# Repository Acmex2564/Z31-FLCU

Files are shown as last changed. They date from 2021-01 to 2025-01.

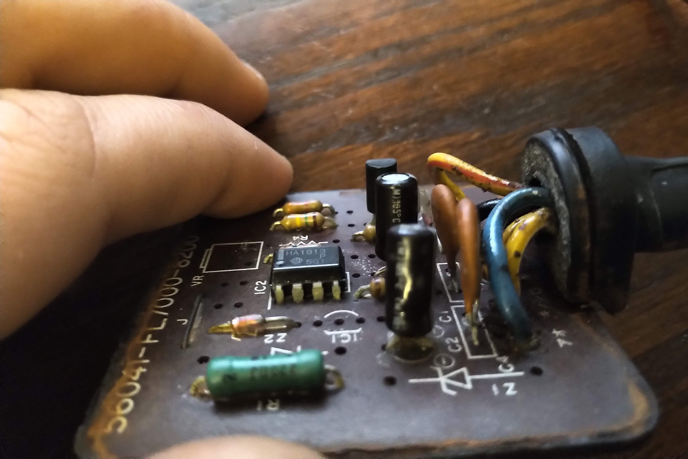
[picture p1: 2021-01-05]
ex_IMG_20210104_2121305.jpg

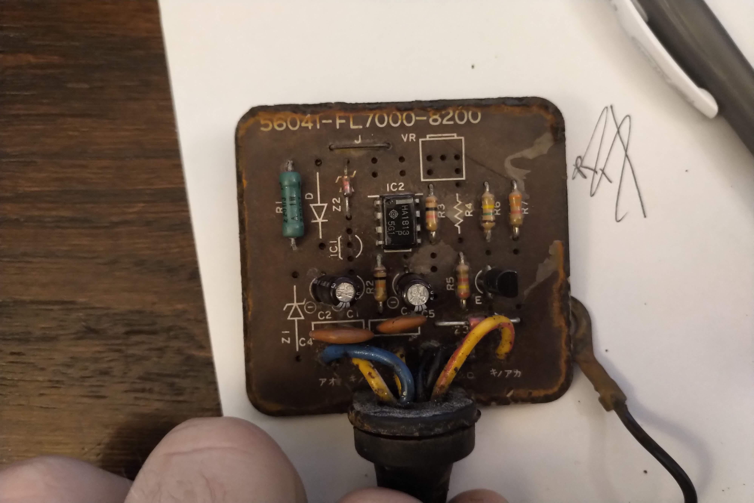
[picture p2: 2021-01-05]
ex_IMG_20200608_1817234.jpg

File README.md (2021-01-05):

# Z31-FLCU
Reverse Engineering of the 300zx (Z31) Analog -> Digital Fuel Tank Gauge Converter Unit

This is a small, silver box located under the hatch of very late Z31s, or cars that have had the original, linear-slide Tank Gauge Sending Unit (TGSU) replaced with the late swing-arm style. 

Analog and digital cars used TGSUs with different resistance curves, to suit the needs of the gauge cluster. The linear-slide parts often demonstrated poor accuracy and high wear-out rates, and the swing arm parts are a commonly sought upgrade. However, Nissan did not produce the same two variants of the later part. Instead, all were produced with the resistance curve for the analog cluster, and if you ordered the replacement part for a digital car you recieved the analog swing-arm, with a small converter box that adjusted the levels to suit the digital cluster.

Now, 30 years later, these simple, hastily-produced boxes are both rare and often affected by corrosion. Their environmental seals are poor, and cases are made of steel in a car with notoriously poor weatherproofing. Perfect for rusting away!

This repository contains my attempt at determing the schematic and method of operation for this tiny circuit. Perhaps one day it will also contain replacement PCB details. 

The key players on the board are:

Zener diode for IC voltage supply (YUP, they removed the actual VR IC to save costs!)
Current limiting resistor to save the Zener
Filter and reservoir caps for the power supply side
Hitachi HA1813P Analog Voltage Comparator
Hitachi D789 NPN transistor
Second Zener diode limiting the voltage from the cluster on the fuel-level sub-gauge sense circuit

In general terms, as far as I can make out this little box lowers the effective resistance for the fuel-level sub-gauge circuit based upon the input from the sending unit on the main gauge sender. I don't know much about digital electronics, and less about linear/analog ones, but it appears that the main level signal is left alone, and left more inaccurate, and the driver should rely on the digital "Fuel Volume remaining" readout on the dash.

Datasheets for the two Hitachi parts are located in the repository, because the datasheet for HA1813PS is difficult to find and I had already saved the other. 
Also found are images of the part in question, and it's wiring harness.

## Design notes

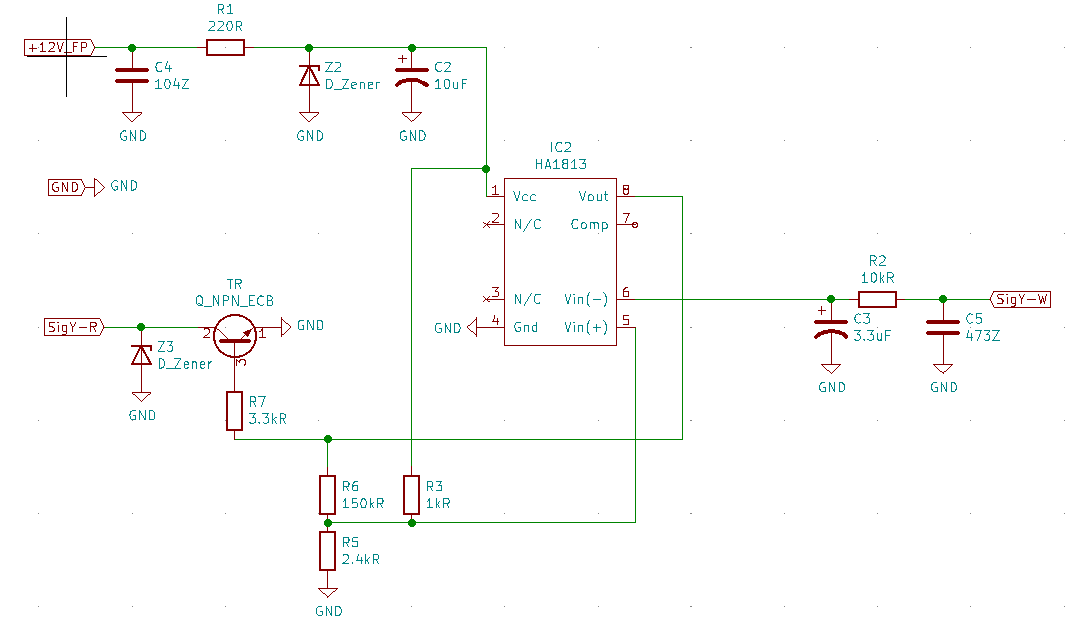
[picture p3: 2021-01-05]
Schematic.PNG

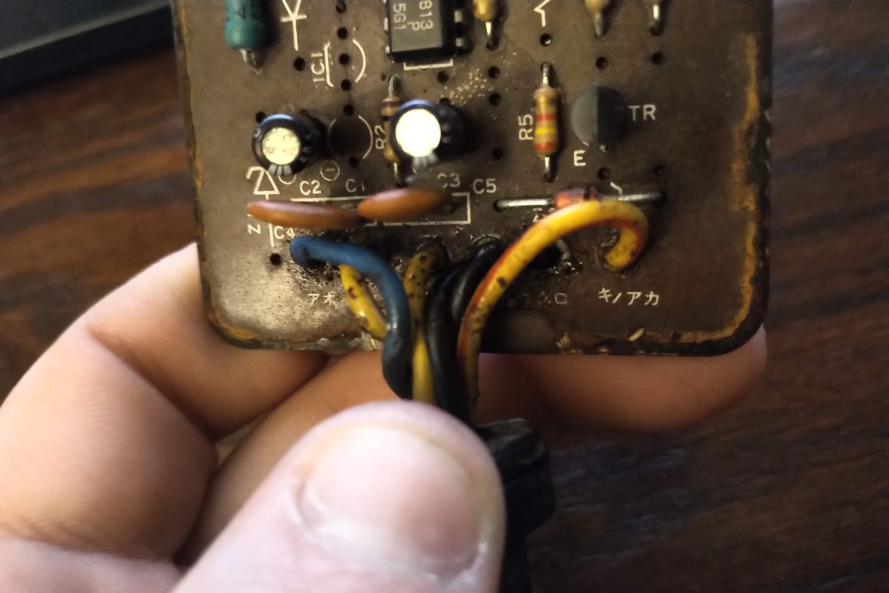
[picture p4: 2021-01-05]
ex_IMG_20210104_2121541.jpg

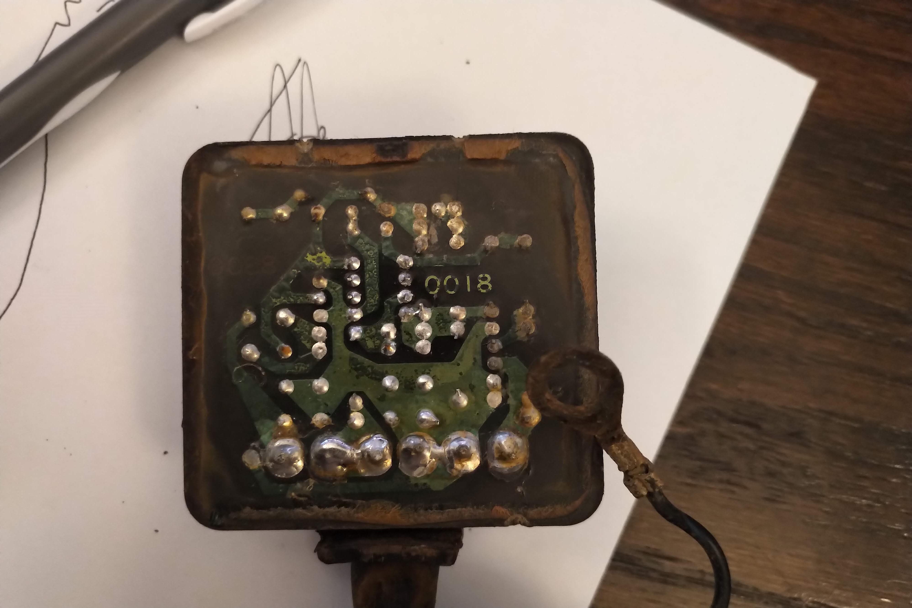
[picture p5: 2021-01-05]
ex_IMG_20200608_1817301.jpg

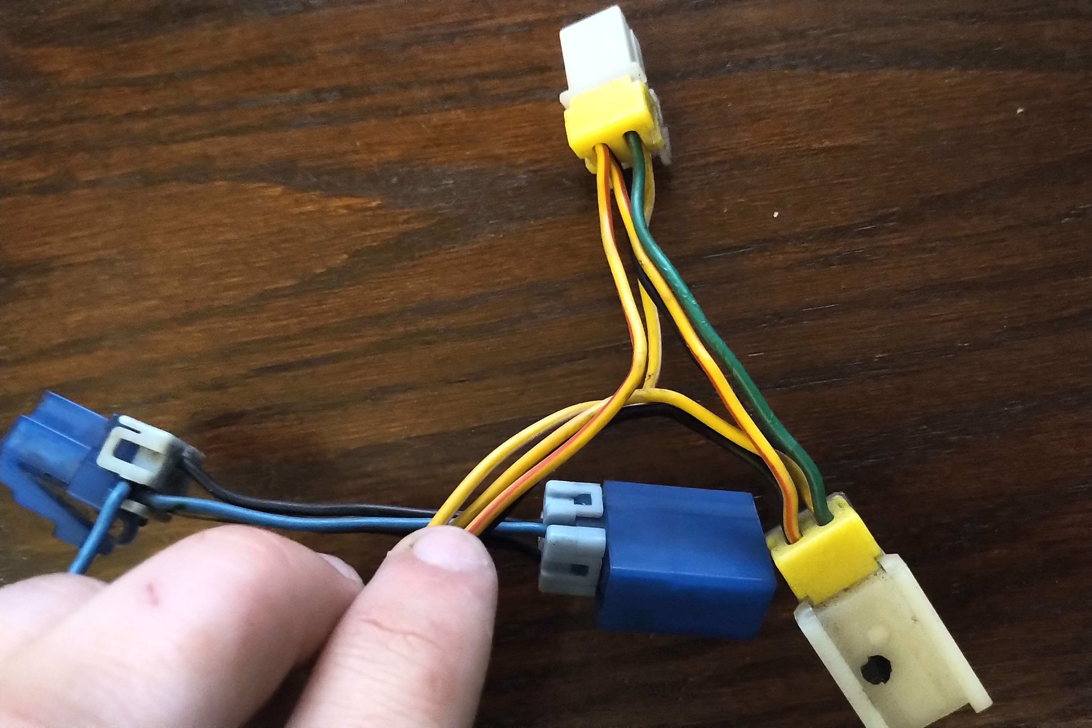
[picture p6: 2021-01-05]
ex_IMG_20210104_2122053.jpg

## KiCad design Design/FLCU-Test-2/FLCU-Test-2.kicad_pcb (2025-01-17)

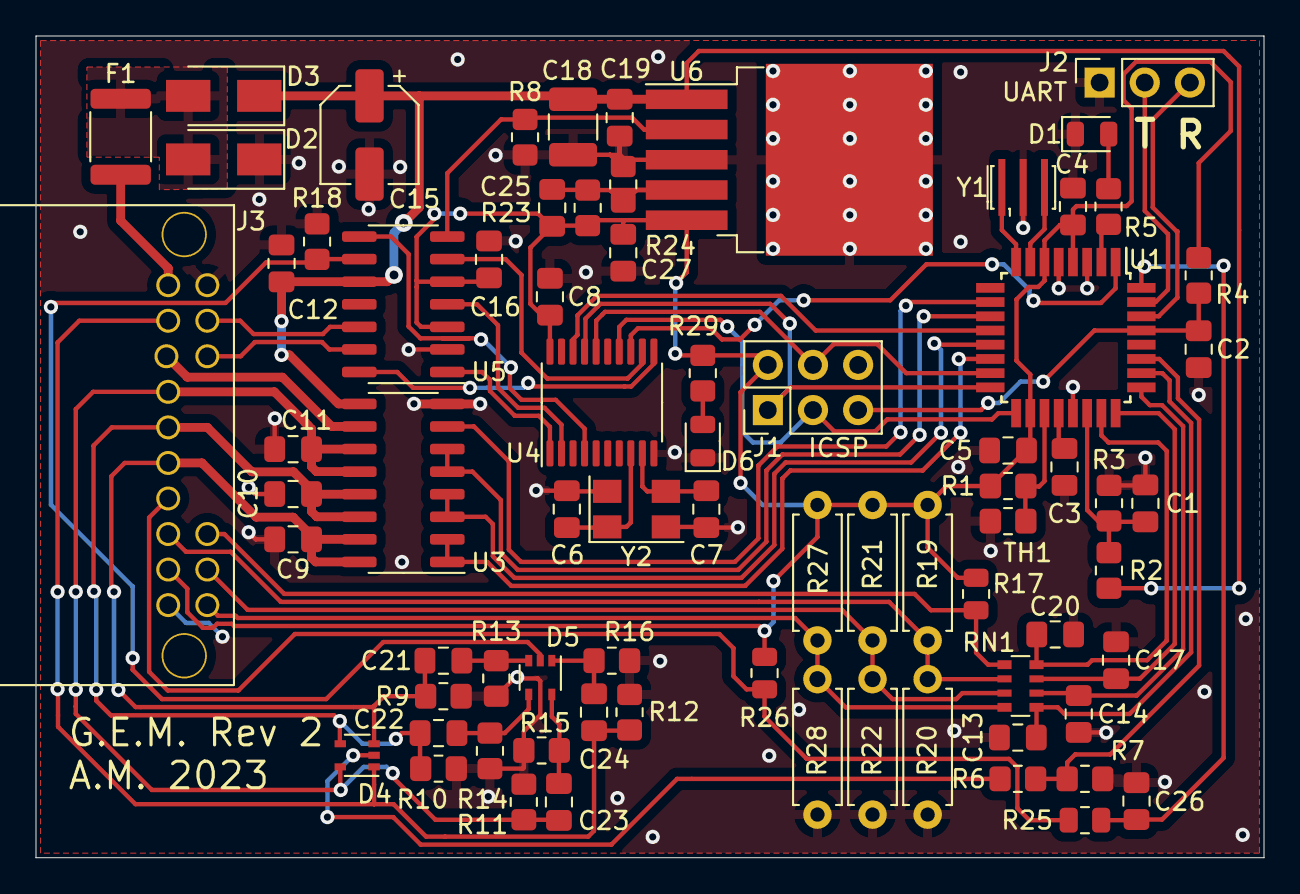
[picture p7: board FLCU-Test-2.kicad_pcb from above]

Board: 2 copper layers, 69.1 x 46.2 mm, 75 parts (0 on the bottom side), 58 nets.

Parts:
C1, C2, C3, C13, C14, C17, C19, C20, C26: 100nF; C_0805_2012Metric_Pad1.18x1.45mm_HandSolder
C4, C5: 1uF; C_0805_2012Metric_Pad1.18x1.45mm_HandSolder
C6, C7: 20pF; C_0805_2012Metric_Pad1.18x1.45mm_HandSolder
C8, C12, C16, C21, C22, C23, C24: 100n; C_0805_2012Metric_Pad1.18x1.45mm_HandSolder
C9, C10, C11, C27: 22uF; C_0805_2012Metric_Pad1.18x1.45mm_HandSolder
C15: 22uF; CP_Elec_5x5.7
C18: 1u; C_1210_3225Metric_Pad1.33x2.70mm_HandSolder
C25: N/A; C_0805_2012Metric_Pad1.18x1.45mm_HandSolder
D1, D6: LED; LED_0805_2012Metric
D2: SMAJ18CAQ-13-F; D_SMA
D3: D; D_SMA
D4, D5: MMBD4448HCQW; SOT-353_SC-70-5
F1: SMD1812P050TF/30; R_1812_4532Metric
J1: ICSP; PinHeader_2x03_P2.54mm_Vertical
J2: UART; PinSocket_1x03_P2.54mm_Vertical
J3: 0348260160
R1, R3: 47k; R_0805_2012Metric_Pad1.20x1.40mm_HandSolder
R2: 150k; R_0805_2012Metric_Pad1.20x1.40mm_HandSolder
R4, R6, R7, R8, R9, R10, R11, R12, R13, R14, R15, R16, R18: 10k; R_0805_2012Metric_Pad1.20x1.40mm_HandSolder
R5, R29: 1K; R_0805_2012Metric_Pad1.20x1.40mm_HandSolder
R17: R; R_0805_2012Metric
R19, R20, R21, R22, R27, R28: R; R_Axial_DIN0207_L6.3mm_D2.5mm_P7.62mm_Horizontal
R23, R24: N/A; R_0805_2012Metric_Pad1.20x1.40mm_HandSolder
R25: 47k; R_0805_2012Metric
R26: 10k; R_0805_2012Metric
RN1: 47K; R_Array_Convex_4x0603
TH1: 47k; R_0805_2012Metric_Pad1.20x1.40mm_HandSolder
U1: ATmega328-AU; TQFP-32_7x7mm_P0.8mm
U3: ULN2003ADR; SOIC-16_3.9x9.9mm_P1.27mm
U4: MCP2515-xST; TSSOP-20_4.4x6.5mm_P0.65mm
U5: TJR1443; SO-14_3.9x8.65mm_P1.27mm
U6: NCV4276B; TO-263-5_TabPin3
Y1: 16MHz; Resonator_SMD_Murata_CSTxExxV-3Pin_3.0x1.1mm_HandSoldering
Y2: 8MHz; Crystal_SMD_5032-4Pin_5.0x3.2mm

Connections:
+5V: C4.2, C5.1, C8.2, C16.2, C25.1, C27.1, J1.2, J3.15, R1.1, R4.1, R17.1, R19.1, R21.1, R23.1, R26.1, R27.1, R29.1, U1.4 (VCC), U1.6 (VCC), U1.18 (AVCC), U4.20 (VDD), U5.3 (Vcc), U5.5 (Vio), U6.5 (OUT)
+12V: C12.2, C15.1, C18.1, C19.1, D3.1 (K), R2.1, U3.9 (COM), U5.10 (Vbat), U6.1 (IN)
+12V_BATTERY: F1.2, J3.7
+12V_IGN: C24.1, D4.1 (A), J3.8, R12.1
/A1_In: J3.6, R27.2, R28.1, RN1.4 (R4.1)
/A2_In: J3.5, R21.2, R22.1, RN1.3 (R3.1)
/A3_In: J3.14, R19.2, R20.1, RN1.2 (R2.1)
/A4_In: J3.4, R17.2, RN1.1 (R1.1)
/CAN_EN: U4.12 (~RX0BF), U5.6 (EN)
/CAN_ERR: U4.4 (~TX0RTS), U5.8 (~ERR)
/CAN_RX: U4.2 (RXCAN), U5.4 (RXCAN)
/CAN_STB: U4.11 (~RX1BF), U5.14 (~STB_N)
/CAN_TX: U4.1 (TXCAN), U5.1 (TXCAN)
/D1_INT_In: J3.13, R25.2, R26.2
/D4: U1.10 (PD6), U3.7 (I7)
/Extra-Out: J3.9, U3.10 (O7)
/Low-Level-Warning-Out: C11.1, C23.1, D4.5 (A), J3.10, R11.1, U3.11 (O6), U3.12 (O5)
/Main-Level-Out: C10.1, C22.1, D4.4 (A), J3.11, R10.1, U3.13 (O4), U3.14 (O3)
/Module-Temperature: R1.2, TH1.1, U1.19 (ADC6)
/Module_Voltage: C1.2, R2.2, R3.1, U1.22 (ADC7)
/POSTFUSE: D2.2 (A2), D3.2 (A), F1.1
/PWM1: U1.13 (PB1), U3.3 (I3), U3.4 (I4)
/PWM2: U1.11 (PD7), U3.5 (I5), U3.6 (I6)
/PWM3: U1.14 (PB2), U3.1 (I1), U3.2 (I2)
/Spare-Analog: C20.2, RN1.8 (R1.2), U1.23 (PC0)
/Sub-Level-Out: C9.1, C21.1, D4.3 (A), J3.12, R9.1, U3.15 (O2), U3.16 (O1)
/VREG_INH: R8.1, U5.7 (INH), U6.2 (~INH)
/Wake_Pulse: D5.2 (K), R18.1, U5.9 (WAKE)
/Wake_Sense: R6.2, R7.1, U1.27 (PC4)
CAN_CS: U1.12 (PB0), U4.18 (~CS)
CAN_H: J3.3, U5.13 (CANH)
CAN_INT: U1.1 (PD3), U4.13 (~INT)
CAN_L: J3.2, U5.12 (CANL)
EXT_INT: C26.2, R25.1, U1.32 (PD2)
GND: C1.1, C2.1, C3.2, C4.1, C5.2, C6.2, C7.2, C8.1, C9.2, C10.2, C11.2, C12.1, C13.1, C14.1, C15.2, C16.1, C17.1, C18.2, C19.2, C20.1, C26.1, C27.2, D1.1 (K), D2.1 (A1), D6.1 (K), J1.6, J2.1, J3.1, J3.16, R3.2, R7.2, R8.2, R9.2, R10.2, R11.2, R12.2, R13.2, R14.2, R15.2, R16.2, R18.2, R20.2, R22.2, R24.2, R28.2, TH1.2, U1.3 (GND), U1.5 (GND), U1.21 (GND), U3.8 (GND), U4.10 (VSS), U5.2 (GND), U6.3 (GND), Y1.2, Y2.2, Y2.4
Low-Level-Warning: C17.2, RN1.7 (R2.2), U1.24 (PC1)
MISO: J1.1, U1.16 (PB4), U4.17 (SO)
MOSI: J1.4, U1.15 (PB3), U4.16 (SI)
Main-Lvl: C13.2, RN1.5 (R4.2), U1.26 (PC3)
unnamed: C3.1, U1.20 (AREF)
unnamed: C6.1, U4.8 (OSC2), Y2.1
unnamed: C7.1, U4.9 (OSC1), Y2.3
unnamed: C21.2, D5.3 (A), R13.1
unnamed: C22.2, D5.4 (A), R14.1
unnamed: C23.2, D5.5 (A), R15.1
unnamed: C24.2, D5.1 (A), R16.1
unnamed: C25.2, R23.2, R24.1, U6.4 (VA)
unnamed: D1.2 (A), R5.2
unnamed: D4.2 (K), R6.1
unnamed: D6.2 (A), R29.2
unnamed: R5.1, U1.2 (PD4)
unnamed: U1.7 (XTAL1/PB6), Y1.3
unnamed: U1.8 (XTAL2/PB7), Y1.1
RESET: C2.2, J1.5, R4.2, U1.29 (~RESET/PC6)
RXD: J2.3, U1.30 (PD0)
SCK: J1.3, U1.17 (PB5), U4.14 (SCK)
Sub-Level: C14.2, RN1.6 (R3.2), U1.25 (PC2)
TXD: J2.2, U1.31 (PD1)

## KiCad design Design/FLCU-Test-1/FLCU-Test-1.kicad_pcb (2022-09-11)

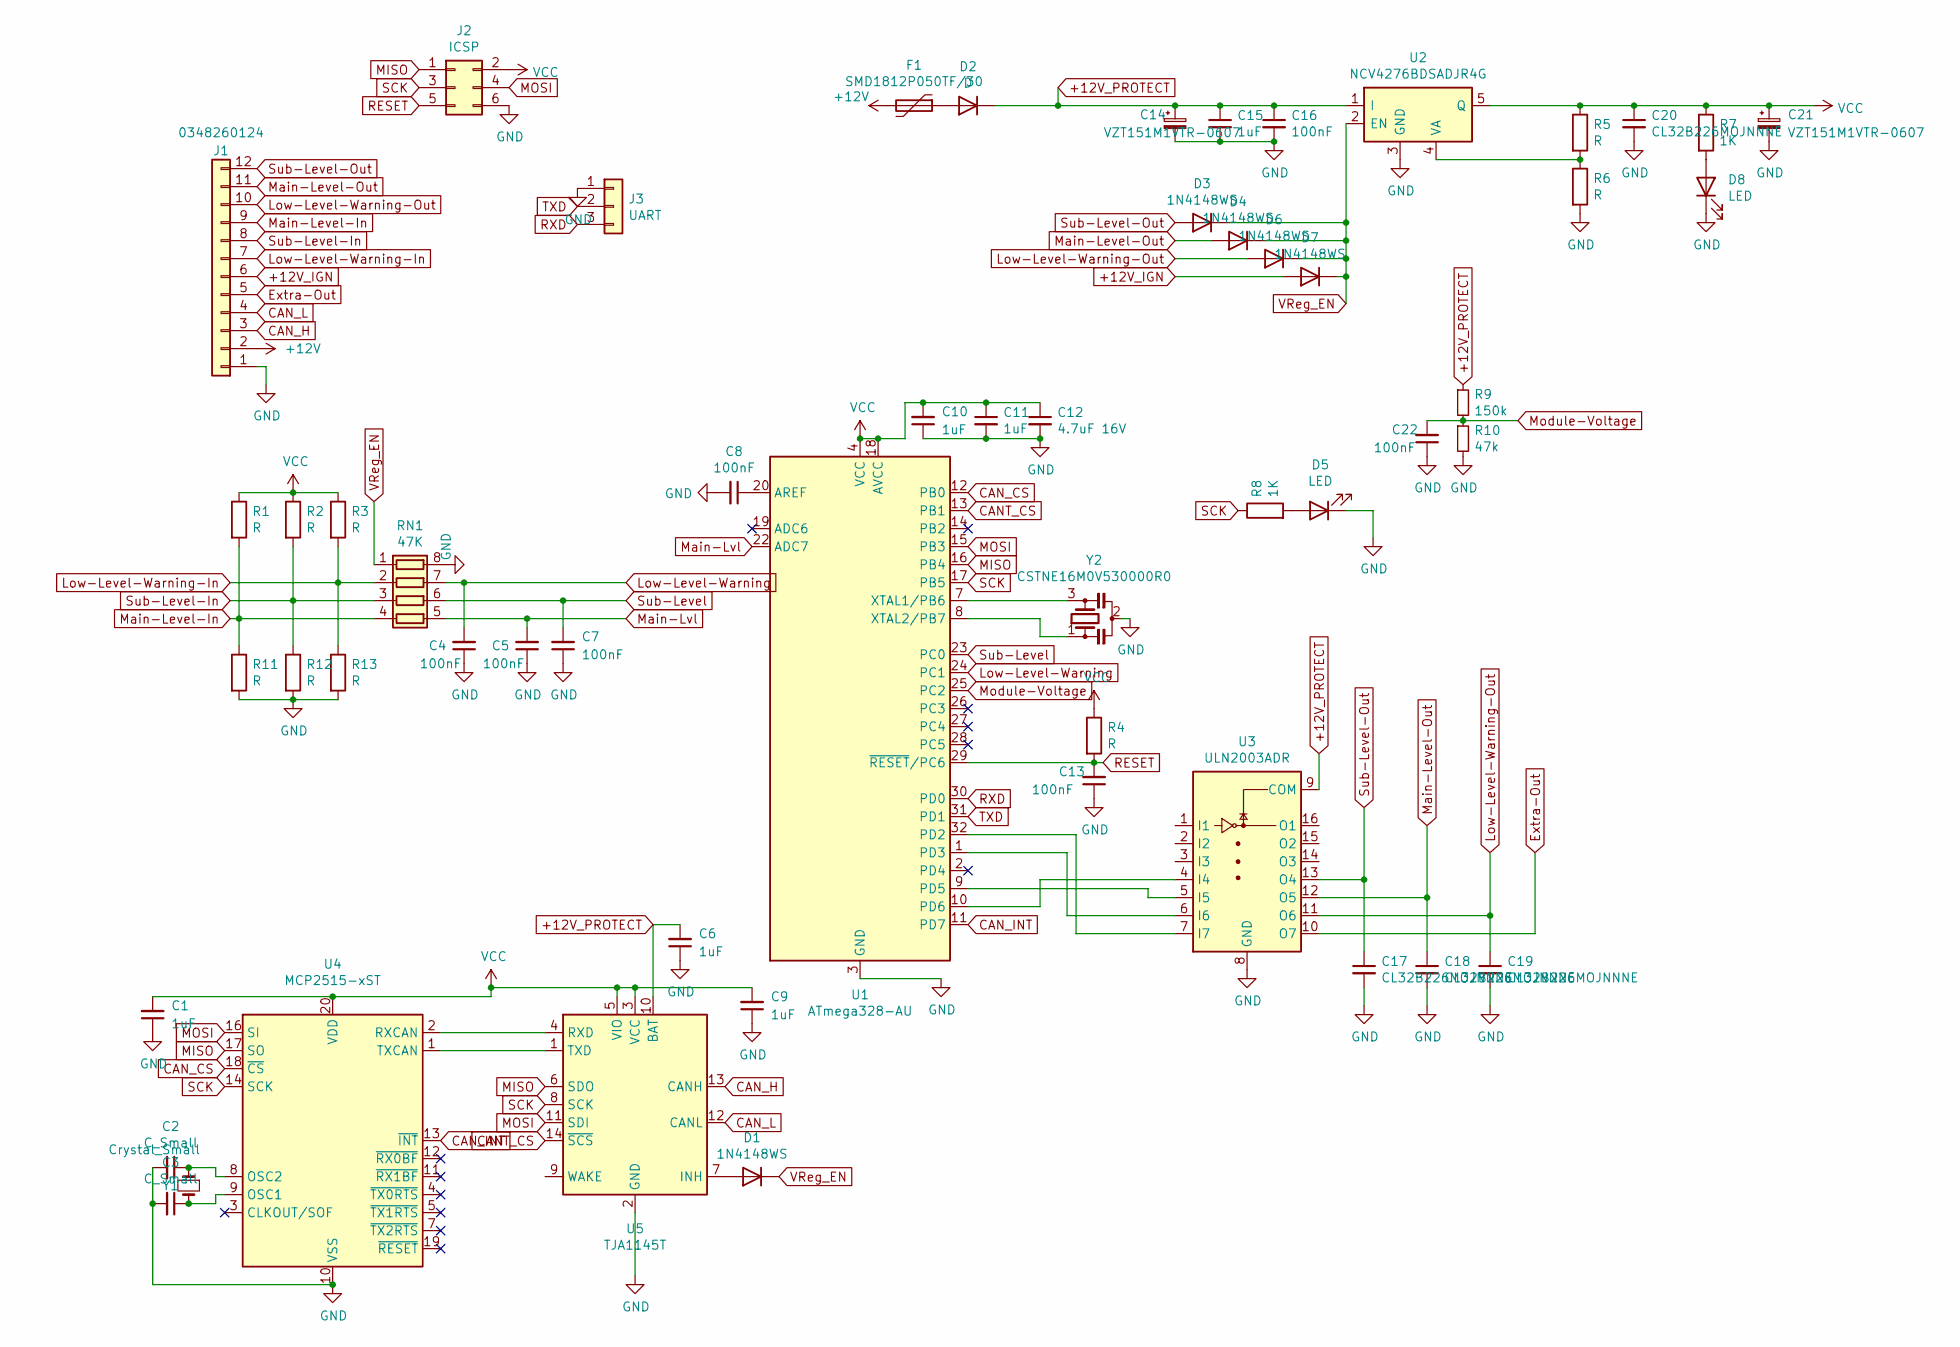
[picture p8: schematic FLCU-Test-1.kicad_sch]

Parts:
C1, C6, C9, C10, C11, C15: 1uF; C_0603_1608Metric
C2, C3: C_Small; C_0603_1608Metric
C4, C5, C7, C8, C13, C16, C22: 100nF; C_0603_1608Metric
C12: 4.7uF 16V; C_0805_2012Metric
C14, C21: VZT151M1VTR-0607; CP_Elec_6.3x7.7
C17, C18, C19: CL32B226MOJNNNE; C_0805_2012Metric_Pad1.18x1.45mm_HandSolder
C20: CL32B226MOJNNNE; C_1210_3225Metric
D1, D3, D4, D6, D7: 1N4148WS; D_SOD-323F
D2: D; D_1210_3225Metric_Pad1.42x2.65mm_HandSolder
D5, D8: LED; LED_0805_2012Metric
F1: SMD1812P050TF/30; R_1812_4532Metric
J1: 0348260124; 034826012-
J2: ICSP; PinHeader_2x03_P2.54mm_Vertical
J3: UART; PinSocket_1x03_P2.54mm_Vertical
R1, R2, R3, R11, R12, R13: R; R_Axial_DIN0207_L6.3mm_D2.5mm_P7.62mm_Horizontal
R4, R5, R6: R; R_0603_1608Metric
R7, R8: 1K; R_0603_1608Metric
R9: 150k; R_0805_2012Metric_Pad1.20x1.40mm_HandSolder
R10: 47k; R_0805_2012Metric_Pad1.20x1.40mm_HandSolder
RN1: 47K; R_Array_Convex_4x0603
U1: ATmega328-AU; TQFP-32_7x7mm_P0.8mm
U2: NCV4276BDSADJR4G; TO-263-5_TabPin3
U3: ULN2003ADR; SOIC-16_3.9x9.9mm_P1.27mm
U4: MCP2515-xST; TSSOP-20_4.4x6.5mm_P0.65mm
U5: TJA1145T; SOIC-14_3.9x8.7mm_P1.27mm
Y1: Crystal_Small; Crystal_HC18-U_Vertical
Y2: CSTNE16M0V530000R0; Resonator_SMD_muRata_CSTxExxV-3Pin_3.0x1.1mm

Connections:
+12V: F1.2, J1.2
+12V_IGN: D7.2 (A), J1.6
+12V_PROTECT: C6.2, C14.1, C15.1, C16.1, D2.1 (K), R9.1, U2.1 (I), U3.9 (COM), U5.10 (BAT)
CANT_CS: U1.13 (PB1), U5.14 (~SCS)
CAN_CS: U1.12 (PB0), U4.18 (~CS)
CAN_H: J1.3, U5.13 (CANH)
CAN_INT: U1.11 (PD7), U4.13 (~INT)
CAN_L: J1.4, U5.12 (CANL)
Extra-Out: J1.5, U3.10 (O7)
GND: C1.1, C2.2, C3.2, C4.1, C5.1, C6.1, C7.1, C8.2, C9.1, C10.1, C11.2, C12.2, C13.1, C14.2, C15.2, C16.2, C17.2, C18.2, C19.2, C20.2, C21.2, C22.1, D5.1 (K), D8.1 (K), J1.1, J2.6, J3.1, R6.2, R10.2, R11.2, R12.2, R13.2, RN1.8 (R1.2), U1.3 (GND), U1.5 (GND), U1.21 (GND), U2.3 (GND), U3.8 (GND), U4.10 (VSS), U5.2 (GND), Y2.2
Low-Level-Warning: C4.2, RN1.7 (R2.2), U1.24 (PC1)
Low-Level-Warning-In: J1.7, R3.2, R13.1, RN1.2 (R2.1)
Low-Level-Warning-Out: C19.1, D6.2 (A), J1.10, U3.11 (O6)
MISO: J2.1, U1.16 (PB4), U4.17 (SO), U5.6 (SDO)
MOSI: J2.4, U1.15 (PB3), U4.16 (SI), U5.11 (SDI)
Main-Level-In: J1.9, R1.2, R11.1, RN1.4 (R4.1)
Main-Level-Out: C18.1, D4.2 (A), J1.11, U3.12 (O5)
Main-Lvl: C5.2, RN1.5 (R4.2), U1.22 (ADC7)
Module-Voltage: C22.2, R9.2, R10.1, U1.25 (PC2)
unnamed: C2.1, U4.8 (OSC2), Y1.1
unnamed: C3.1, U4.9 (OSC1), Y1.2
unnamed: C8.1, U1.20 (AREF)
unnamed: D1.2 (A), U5.7 (INH)
unnamed: D2.2 (A), F1.1
unnamed: D5.2 (A), R8.2
unnamed: D8.2 (A), R7.2
unnamed: R5.2, R6.1, U2.4 (VA)
unnamed: U1.1 (PD3), U3.6 (I6)
unnamed: U1.7 (XTAL1/PB6), Y2.3
unnamed: U1.8 (XTAL2/PB7), Y2.1
unnamed: U1.9 (PD5), U3.5 (I5)
unnamed: U1.10 (PD6), U3.4 (I4)
unnamed: U1.32 (PD2), U3.7 (I7)
unnamed: U4.1 (TXCAN), U5.1 (TXD)
unnamed: U4.2 (RXCAN), U5.4 (RXD)
RESET: C13.2, J2.5, R4.2, U1.29 (~RESET/PC6)
RXD: J3.3, U1.30 (PD0)
SCK: J2.3, R8.1, U1.17 (PB5), U4.14 (SCK), U5.8 (SCK)
Sub-Level: C7.2, RN1.6 (R3.2), U1.23 (PC0)
Sub-Level-In: J1.8, R2.2, R12.1, RN1.3 (R3.1)
Sub-Level-Out: C17.1, D3.2 (A), J1.12, U3.13 (O4)
TXD: J3.2, U1.31 (PD1)
VCC: C1.2, C9.2, C10.2, C11.1, C12.1, C20.1, C21.1, J2.2, R1.1, R2.1, R3.1, R4.1, R5.1, R7.1, U1.4 (VCC), U1.6 (VCC), U1.18 (AVCC), U2.5 (Q), U4.20 (VDD), U5.3 (VCC), U5.5 (VIO)
VReg_EN: D1.1 (K), D3.1 (K), D4.1 (K), D6.1 (K), D7.1 (K), RN1.1 (R1.1), U2.2 (EN)

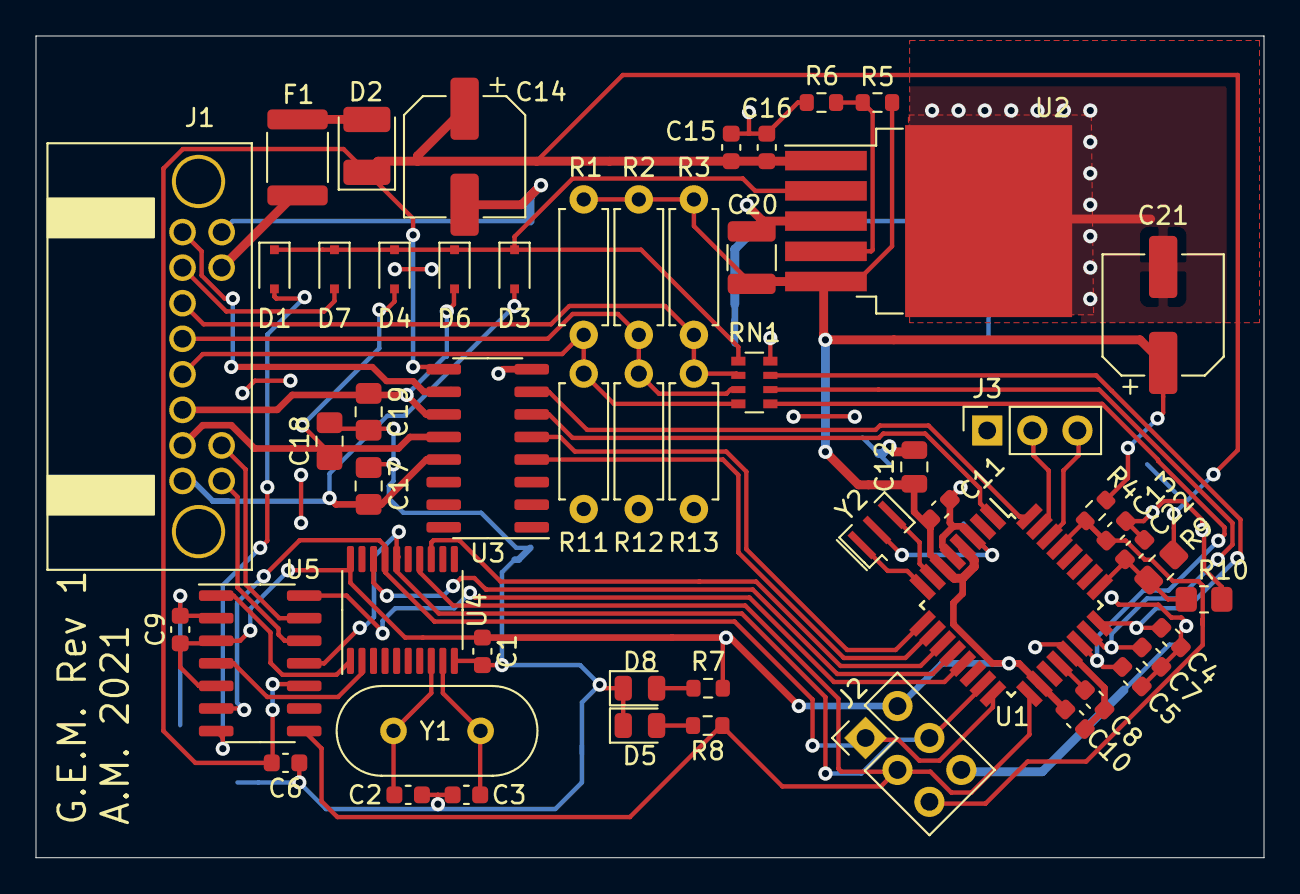
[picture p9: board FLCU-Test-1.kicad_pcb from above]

Board: 2 copper layers, 69.1 x 46.2 mm, 55 parts (0 on the bottom side), 44 nets.

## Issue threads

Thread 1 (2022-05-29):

Wrong CAN transceiver

Acmex2564, 2022-05-29:
Poor selection of CAN transceiver initially. Switch to TJR1443 (personal standard) and connect EN/STB/ERR pins via MCP2515 GPIJO.

Saves one pin on MCU.

Regulator INH should be connected to transceiver INH output w/pulldown.

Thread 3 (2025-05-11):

Clarification on this device

harknesslabs, 2025-05-11:
Hi!

First off, you should join the z31 discord ( https://discord.gg/mdpn6pnWHh )

Second off, Its been said that its a common myth this is a converter to let the new fuel sender units work with analog boxes. Its a leveling device of some sort, designed to even out the readings.

Actually, I hope it is what you say it is because then you can join the above discord and tell our resident EE that hes wrong and it would give me great joy to see him admit defeat.

Anyways, have a great day!

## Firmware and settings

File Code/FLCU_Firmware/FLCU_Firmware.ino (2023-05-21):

//Libaries
#include <mcp_can.h>

//Pin assignments
#define MAIN_IN A7
#define MAIN_OUT 5

#define SUB_IN A0
#define SUB_OUT 6

#define LL_IN A1
#define LL_OUT 3

#define AUX_OUT 2

#define MODULE_VOLTAGE A2

#define LED 13

#define CAN_INT 7
#define CAN_CS 8
#define CANT_CS 9

#define HIST_ARRAY_SIZE 5

#define NUM_MAIN 20
#define NUM_MAIN_OUT 21
#define NUM_SUB 10

#define SERIAL_SPEED 9600




unsigned long timeCurrent = 0;
const unsigned int intervalReadLevels = 200;
unsigned long timeLastRead = 0;
const unsigned int intervalSerialStatus = 2000;
unsigned long timeLastStatus = 0;
const unsigned int intervalBlink = 1000;
unsigned long timeLastBlink;

const unsigned int intervalCan = 1000;
unsigned long timeLastCan = 0;

MCP_CAN CAN0(CAN_CS);
const unsigned long int idPacketLevelOut = 0x720;
const uint8_t canTxLen = 6;
uint8_t canTxBuf[8];
byte canSendStat; 

//Calibration Constants

// Module Voltage
// 150k and 47k
const float divVolts = (150.0+47.0) / 47.0 ;

// Fuel level senders are configured as voltage dividers
// Here we have two, configured as "Main" and "Sub"
// Variables "t_" represent the resistor value on the top side of the divider
// Variables "b_Min" and "b_Max" represent the range of expected resistance values in the tank
// All resistance values are times 100 to keep the math as integers
int tMain = 110;
int tSub = 235;

int rMain[NUM_MAIN] = {
  80, 72,
  66, 61,
  56, 51,
  45, 42, 
  38, 34,
  31, 29, 
  26, 23,
  19, 14,
  10, 5,
  3, 1
};


int rSub[NUM_SUB] = {
  3, 6,
  12, 19,
  30, 49,
  96, 127,
  273, 275
};

int oMain[NUM_MAIN_OUT] = {
  13, 15, 
  17, 22,
  28, 34, 
  43, 52,
  62, 69,
  80, 96,
  112, 122, 
  139, 157,
  170, 188, 
  211, 230, 
  246
};

int oSub[NUM_SUB]= {
  13, 21,
  29, 47,
  107, 180,
  232, 237,
  243, 246
};

int levelPrevPos = 0;

void setup() {
  // put your setup code here, to run once:

pinMode(MAIN_IN, INPUT);
pinMode(SUB_IN, INPUT);
pinMode(LL_IN, INPUT);
pinMode(MODULE_VOLTAGE, INPUT);
pinMode(CAN_INT, INPUT);

pinMode(MAIN_OUT, OUTPUT);
pinMode(SUB_OUT, OUTPUT);
pinMode(LL_OUT, OUTPUT);
pinMode(AUX_OUT, OUTPUT);
pinMode(LED, OUTPUT);
pinMode(CAN_CS, OUTPUT);
pinMode(CANT_CS, OUTPUT);

Serial.begin(SERIAL_SPEED);

//TCCR0B = TCCR0B & B11111000 | B00000010; // for PWM frequency of 7812.50 Hz
TCCR2B = TCCR2B & B11111000 | B00000010; // for PWM frequency of 3921.16 Hz
  writeLevel(NUM_MAIN_OUT, oMain, readLevel(NUM_MAIN, rMain, false, tMain, analogRead(MAIN_IN)), MAIN_OUT );
  writeLevel(NUM_SUB, oSub, readLevel(NUM_SUB, rSub, true, tSub, analogRead(SUB_IN)), SUB_OUT );

//  digitalWrite(CAN_RESET, HIGH);
  //delay(50);
  digitalWrite(CANT_CS, LOW);
  int canstat = CAN0.begin(MCP_ANY, CAN_500KBPS, MCP_8MHZ);
  if (canstat == CAN_OK)
  {
    Serial.println("MCP2515 Initialized Successfully!");
  }
  else
  {
    Serial.print("Error Initializing MCP2515..."); Serial.println(canstat);
  }
  // can controller into normal mode
  CAN0.setMode(MCP_NORMAL);



}

void loop() {
  // put your main code here, to run repeatedly:

  timeCurrent = millis();

  if (timeCurrent - timeLastRead > intervalReadLevels)
  {

  digitalWrite(LED, HIGH);
  writeLevel(NUM_MAIN_OUT, oMain, readLevel(NUM_MAIN, rMain, false, tMain, analogRead(MAIN_IN)), MAIN_OUT );
  
  
  writeLevel(NUM_SUB, oSub, readLevel(NUM_SUB, rSub, true, tSub, analogRead(SUB_IN)), SUB_OUT );
  timeLastRead = timeCurrent;
  digitalWrite(LED, LOW);
  }

  if (timeCurrent - timeLastStatus > intervalSerialStatus)
  {
      
    Serial.println("Heartbeat");
    Serial.print("Module Volts:"); Serial.println((analogRead(MODULE_VOLTAGE) * 5.0 / 1023.0) * divVolts);
    Serial.print("Supply Volts:"); Serial.println(readVcc());
    Serial.print(" Main Level (Gal): "); Serial.println(readLevel(NUM_MAIN, rMain, false, tMain, analogRead(MAIN_IN)));
    Serial.print(" Main Level (PWM): "); Serial.println(writeLevel(NUM_MAIN_OUT, oMain, readLevel(NUM_MAIN, rMain, false, tMain, analogRead(MAIN_IN)), MAIN_OUT ));
    Serial.print(" Sub Level (Gal): "); Serial.println(readLevel(NUM_SUB, rSub, true, tSub, analogRead(SUB_IN)));
    Serial.print(" Sub Level (PWM): "); Serial.println(writeLevel(NUM_SUB, oSub, readLevel(NUM_SUB, rSub, true, tSub, analogRead(SUB_IN)), SUB_OUT ));
    timeLastStatus = timeCurrent;
  }
  

  if (timeCurrent - timeLastCan > intervalCan)
  {
    canTxBuf[0] = readLevel(NUM_MAIN, rMain, false, tMain, analogRead(MAIN_IN)) * 10;
    canTxBuf[1] = readLevel(NUM_SUB, rSub, true, tSub, analogRead(SUB_IN)) * 10;
    canTxBuf[2] = 0xFF;
    canTxBuf[3] = 0xFF;
    canTxBuf[4] = 0xFF;
    canTxBuf[5] = 0xFF;
    canSendStat = CAN0.sendMsgBuf(idPacketLevelOut, 0, canTxLen, canTxBuf);
    if (canSendStat == CAN_OK){
      Serial.println("CanOK");
    }
    else {
      Serial.print("CanErr: "); Serial.println(canSendStat);
    }
    timeLastCan = timeCurrent;
    
  }

  
  

}

long readVcc() {
  long result;
  // Read 1.1V reference against AVcc
  ADMUX = _BV(REFS0) | _BV(MUX3) | _BV(MUX2) | _BV(MUX1);
  delay(2); // Wait for Vref to settle
  ADCSRA |= _BV(ADSC); // Convert
  while (bit_is_set(ADCSRA,ADSC));
  result = ADCL;
  result |= ADCH<<8;
  result = 1125300L / result; // Back-calculate AVcc in mV
  return result;
}

int writeLevel(int numElem, int * table, float level, int pinOut) {
  int index;
  int result;

  index = constrain(floor(level), 0, numElem-1);

  level = floor(level*100.0);
  level = (int)level;
  //Serial.print("  Index: "); Serial.println(index);
  
  
  
  result = map(level, index*100, (index+1)*100, table[index], table[index+1] );
  analogWrite(pinOut, result);
  return result;
  //Serial.print("  PWM: "); Serial.println(result);
};

float readLevel(int numElem, int * table, bool reverse, int rTop, int reading) {
  float reading2;
  float result;
  int index;

  //convert adc reading to resistance
  reading2 = constrain(reading, 1, 1023);
  reading2 = rTop / (((1024.0)/(reading))-1);
  //Serial.print("  Reading (Ohm): "); Serial.println(reading2);
  
  //cycle through lookup table until value is greater than (normal) or less than (reverse)the current table value
  for (index = 0; index <= numElem - 1; index++) 
  {
    //Serial.println(index);
    if ((!reverse && reading2 >= table[index]) || ( reverse && reading2 <= table[index])) 
    {
      break;
    }   
  }
  
  //linear interpolation between last and next value
  if (index < numElem-1) 
  {
    result = float(index-1) + ((reading2 - float(table[index-1])) * ((float(index) - float(index-1))/float(table[index] - table[index-1])));
  }
  else
  {
    result = index;
  }
  //Serial.print("  Level   (Gal): "); Serial.println(result);

  return result;
}

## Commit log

2022-09-11 Add design files to repository
    [FLCU-Test-1.kicad_pcb, FLCU-Test-1.kicad_sch, FLCU-Test-1.sch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]
2022-09-29 Include arduino sketch
2023-05-21 Tentative Completion of Rev2 of FLCU / GEM - Switch to TJR1443 CAN transceiver - Smaller, more modern crystal for MCP2515 - Pulse-forming network to use sleep/wake functionality of TJR1443 - Switch f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
    This revision was done to correct some sleep/wake issues with Rev1, and to support it's use as a boost controller (with different FW)
    - Out - PWM Boost Control Solenoid
    - Out - PWM Electric Water Pump (Intercooler)
    - Out - Intercooler Fan Relay
    - DIn - Turbine speed
    - AIn - Manifold Pressure
    - AIn - Discharge Air T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
    [FLCU-Test-2.kicad_pcb, FLCU-Test-2.kicad_sch]
2023-05-21 Updated firmware for Rev1 FLCU (Serial printout and sleep/wake tweaks)
2025-01-17 GEM Rev2 (formerly FLCU Rev2) design & layout complete.
    [FLCU-Test-2.kicad_pcb, FLCU-Test-2.kicad_sch]
